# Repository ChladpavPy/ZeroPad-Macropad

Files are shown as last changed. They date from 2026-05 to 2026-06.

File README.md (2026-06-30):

# ZeroPad - Custom Macropad

The pathfinder project is great hardware introduction project, but I wanted to do bit more, that I would use daily - specifically for quick shortcuts as a keyboard to my computer.

I designed a custom PCB in KiCad featuring a 2x3 matrix with 6 mechanical Cherry MX switches, and I also added a 4-pin header for a 0.91 I2C OLED display. The display is intended to show the currently active macro profile (such as gaming Mode or work Mode). The board layout was carefully optimized for standard 1U keycap spacing to avoid keycaps collisions.

## Project Features

* **Microcontroller:** Seeed Studio XIAO RP2040
* **Switches:** 6x Mechanical Cherry MX Switches
* **Display:** 0.91 I2C OLED Display for active mode rendering
* **Status LEDs:** 3x basic LEDs for hardware debugging/status
* **PCB Design:** Custom 2-layer board routed in KiCad with dual Cu GND pours for a clean finish.

## Gallery

### Build Preview
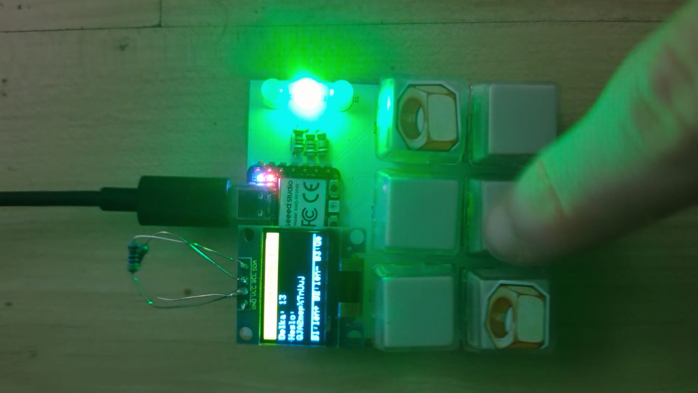
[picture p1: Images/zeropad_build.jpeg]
Build Preview

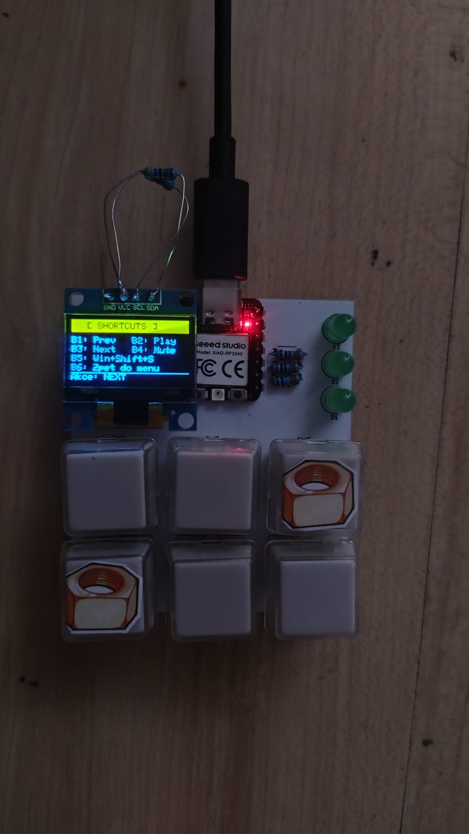
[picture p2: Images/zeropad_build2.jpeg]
Build Preview

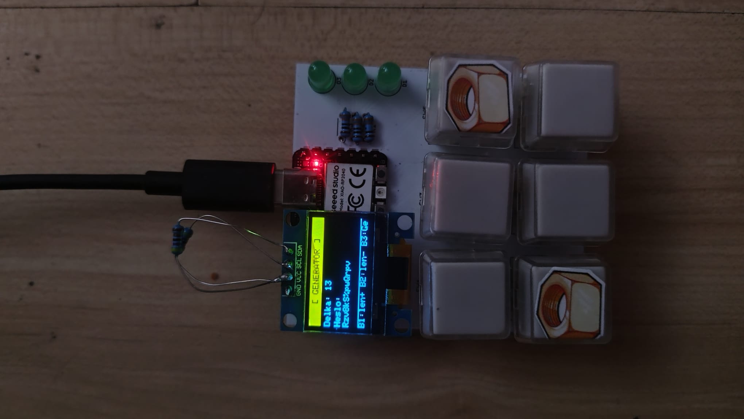
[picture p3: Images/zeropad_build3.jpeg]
Build Preview


### 3D Assembly Renders
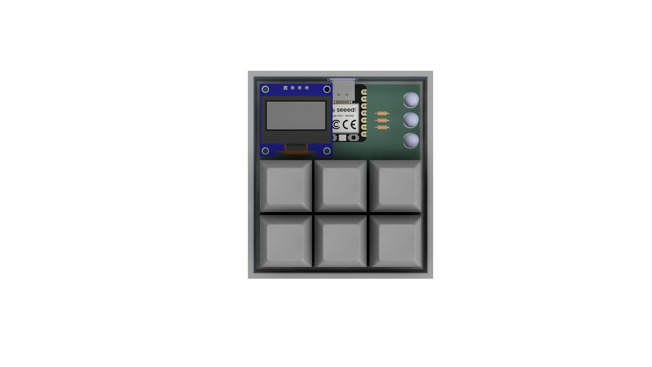
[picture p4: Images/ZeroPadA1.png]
ASSEMBLY_1

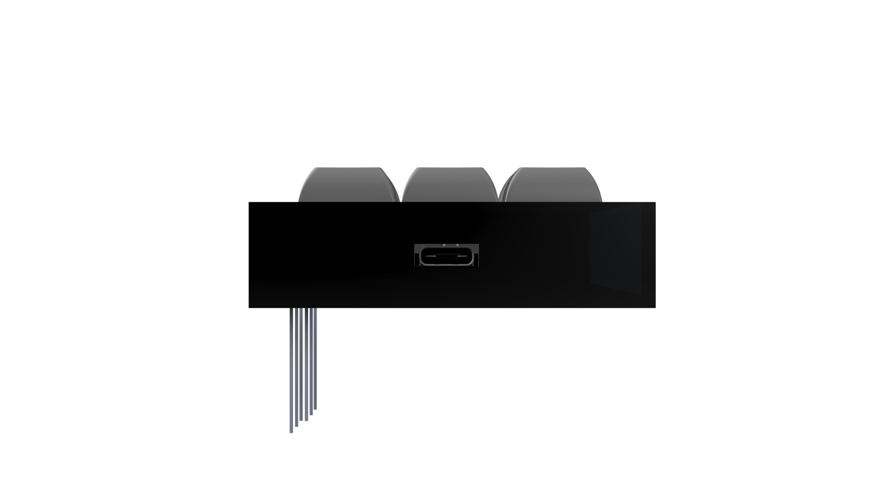
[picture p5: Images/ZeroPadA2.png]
ASSEMBLY_2

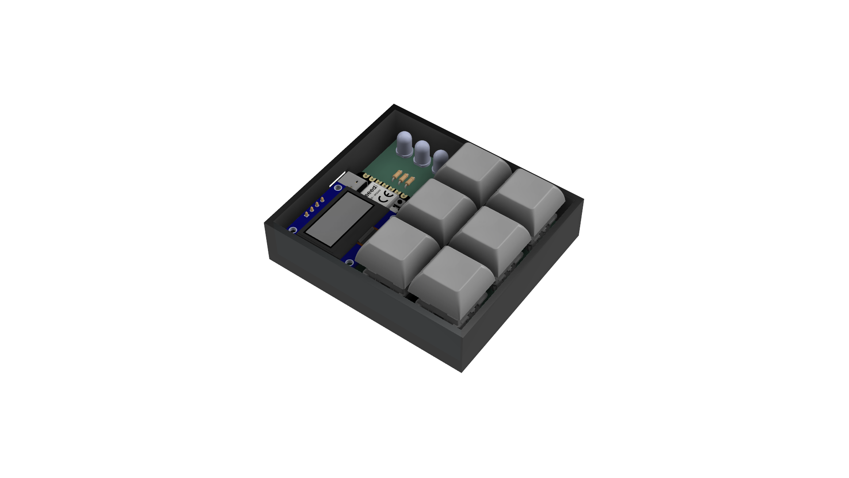
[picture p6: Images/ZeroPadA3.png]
ASSEMBLY_3


### 3D PCB Renders
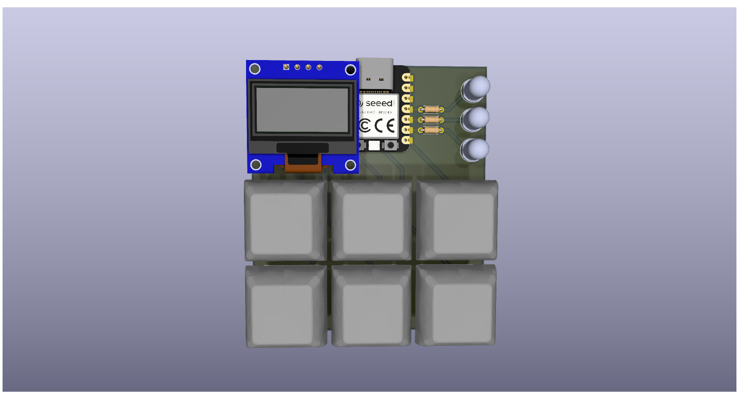
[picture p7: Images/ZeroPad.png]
PCB 3D 1

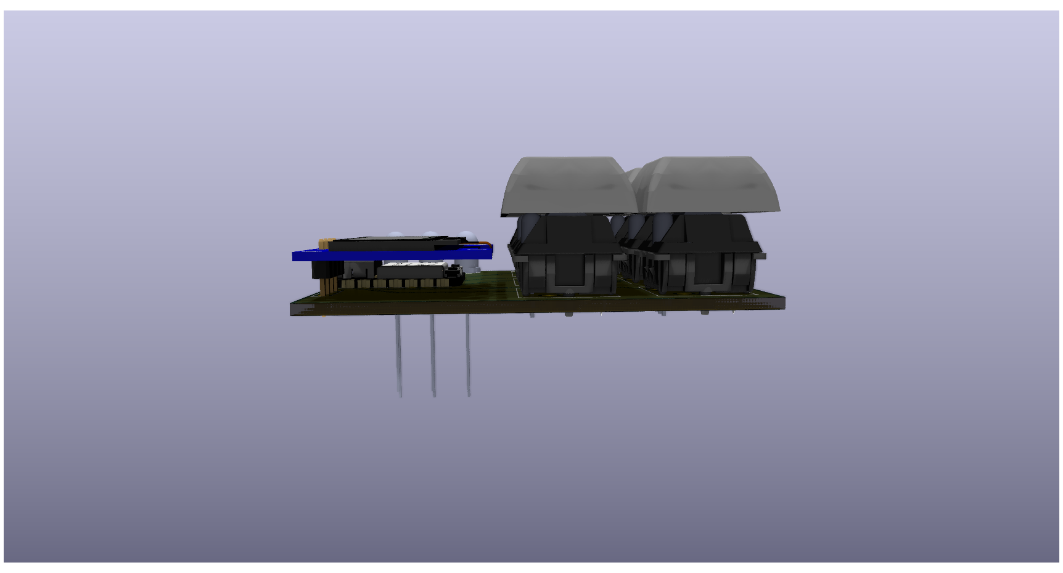
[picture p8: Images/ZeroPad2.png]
PCB 3D 2

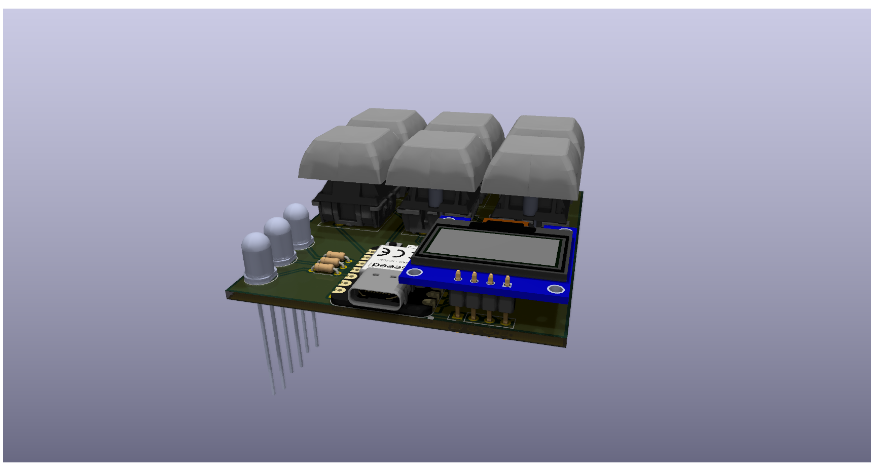
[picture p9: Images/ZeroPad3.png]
PCB 3D 3


### PCB Routing & Schematic
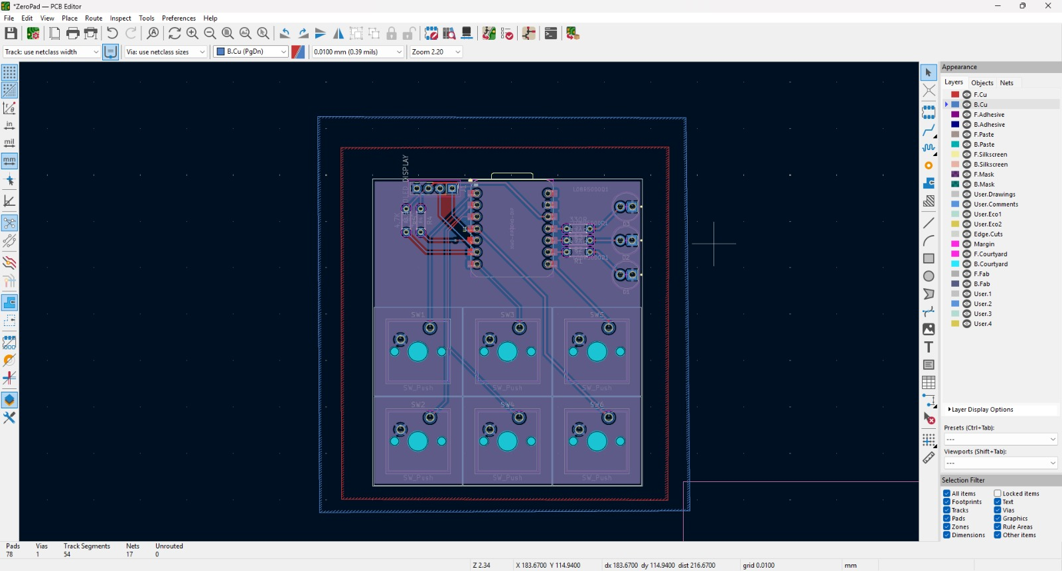
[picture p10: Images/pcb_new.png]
PCB Front

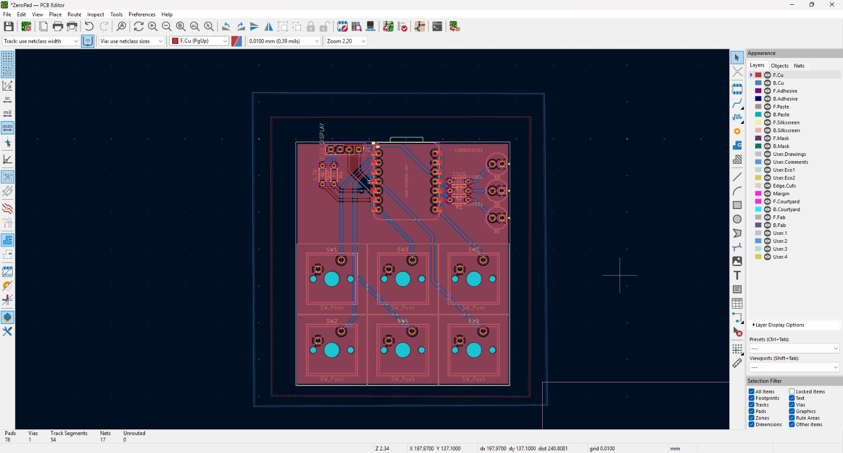
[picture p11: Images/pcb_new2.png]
PCB Back

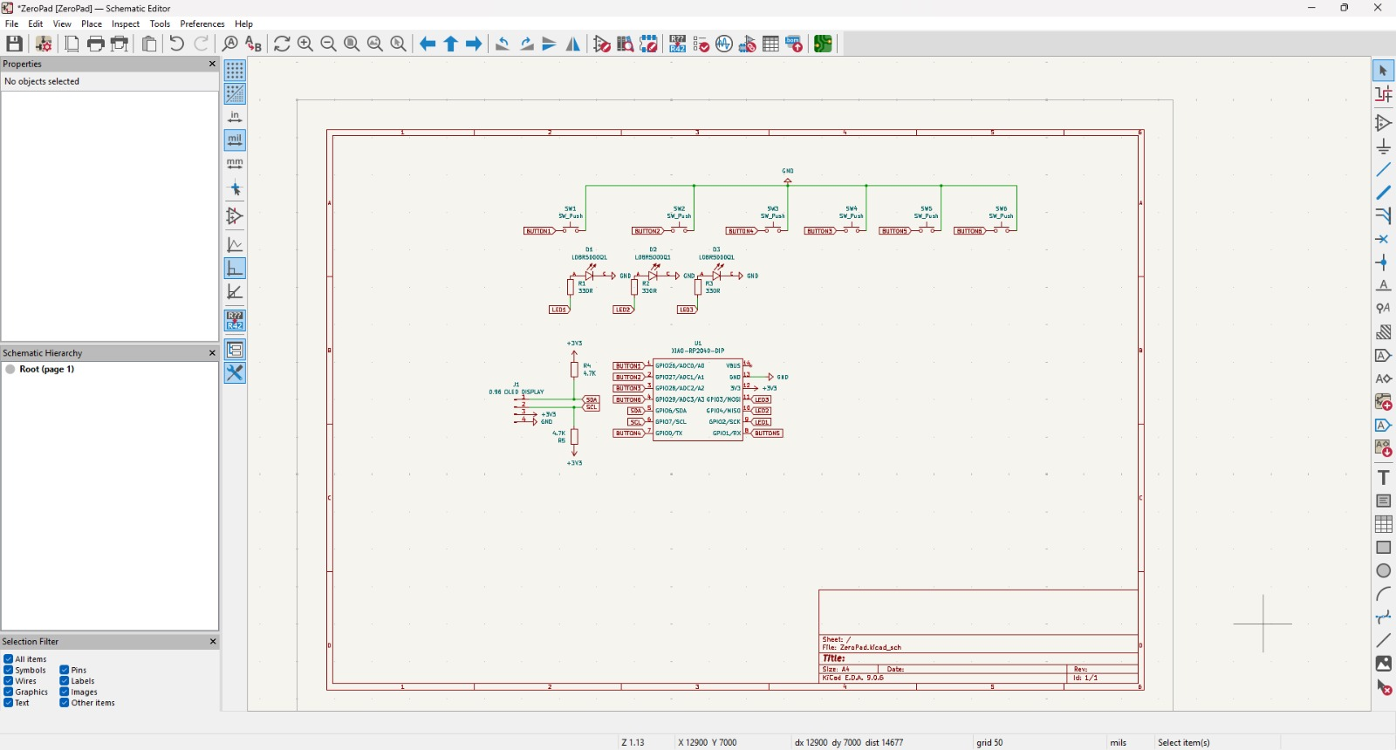
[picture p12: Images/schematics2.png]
Schematic


---

## Bill of Materials (BOM)

| Component | Qty | Purpose / Description | Price (USD) | Link / Distributor |
| :--- | :---: | :--- | :--- | :--- |
| **Custom PCB Manufacture** | 5 | The actual circuit board to solder everything on. Ordered via JLCPCB standard 2-layer service. | ~$4.74 | [JLCPCB](https://jlcpcb.com) |
| **Seeed Studio XIAO RP2040** | 1 | Main microcontroller / brain for the macropad. Small footprint, plenty of GPIOs. | ~$7.88 | [AliExpress](https://a.aliexpress.com/_EyHIJs2) |
| **0.96" I2C OLED Display** | 1 | Screen to show active macro profiles and current modes. | ~$2.00 | [AliExpress](https://a.aliexpress.com/_EGSrJ7g) |
| **Cherry MX Switches (10-pack)** | 1 | Mechanical switches for the macro buttons. | ~$6.08 | [AliExpress](https://a.aliexpress.com/_EuLENRY) |
| **1U Blank Keycaps (10-pack)** | 1 | Standard covers for the mechanical switches. | ~$3.35 | [AliExpress](https://a.aliexpress.com/_Eyx6JJo) |
| **5mm Green LEDs** | 3 | Status LEDs for debugging (Bought locally, link is equivalent). | ~$0.50 | [SparkFun](https://www.sparkfun.com/products/9592) |
| **330 Ohm Resistors** | 3 | Current limiting resistors for the LEDs (Bought locally). | ~$0.50 | [SparkFun](https://www.sparkfun.com/resistor-330-ohm-1-6th-watt-pth.html) |
| **4.7k Ohm Resistors** | 2 | I2C pull-up resistors for stable OLED communication. | ~$0.50 | [Dratek.cz](https://dratek.cz/arduino-platforma/174921-metalizovany-rezistor-4k7-5w-1.html) |

---

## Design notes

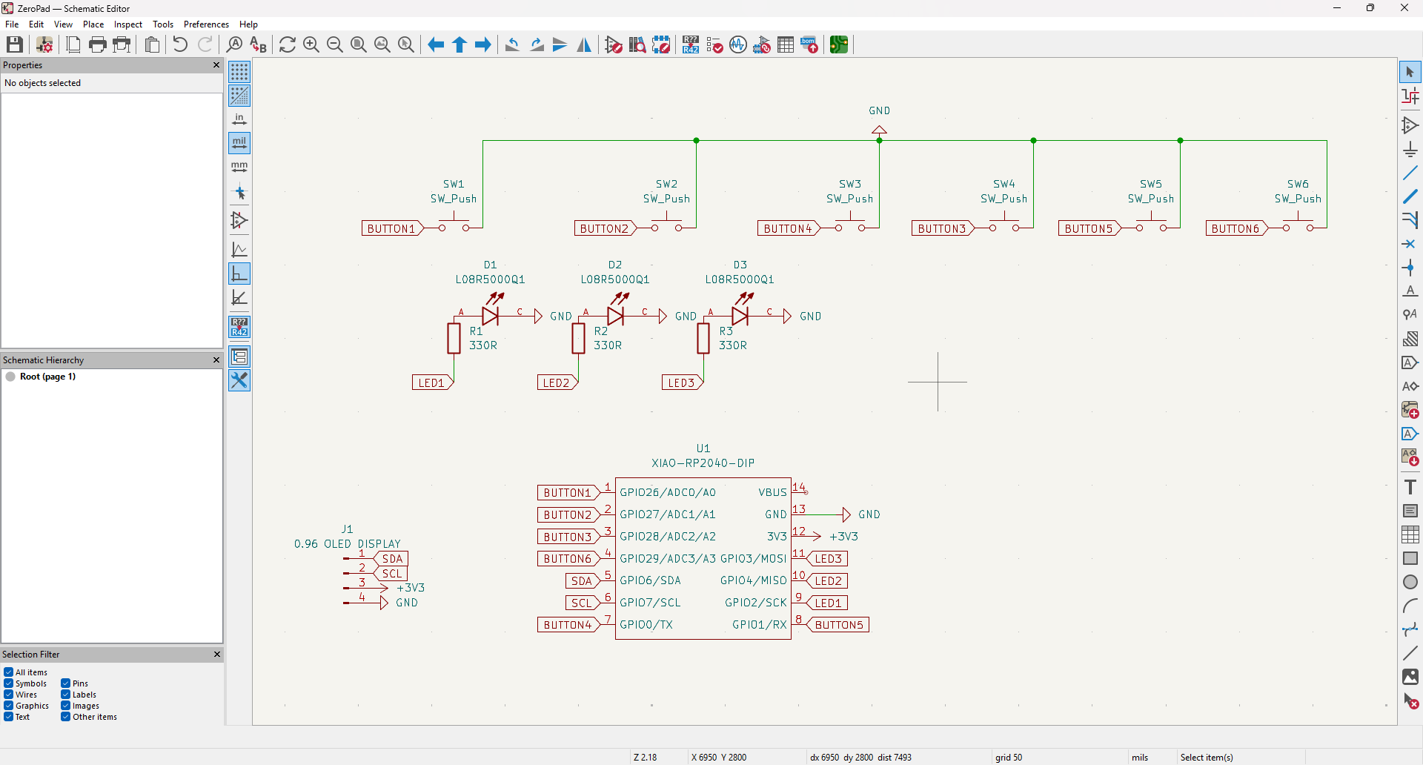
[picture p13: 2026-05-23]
Images/schematics.png

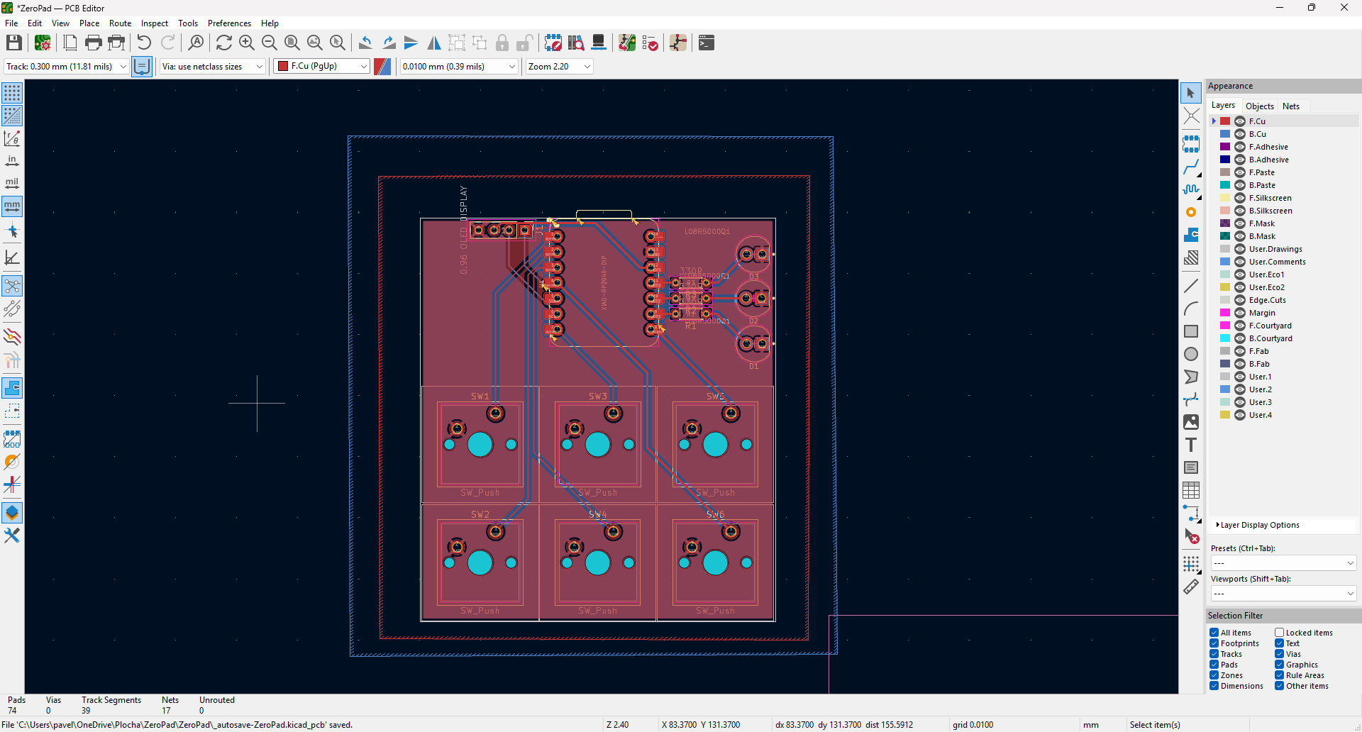
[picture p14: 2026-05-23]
Images/pcb_f.png

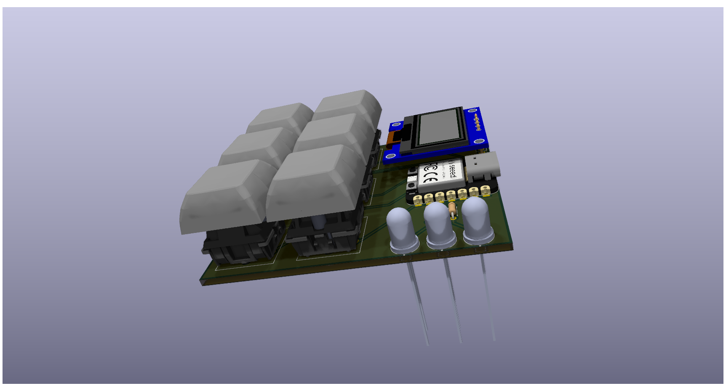
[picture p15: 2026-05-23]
Images/ZeroPad4.png

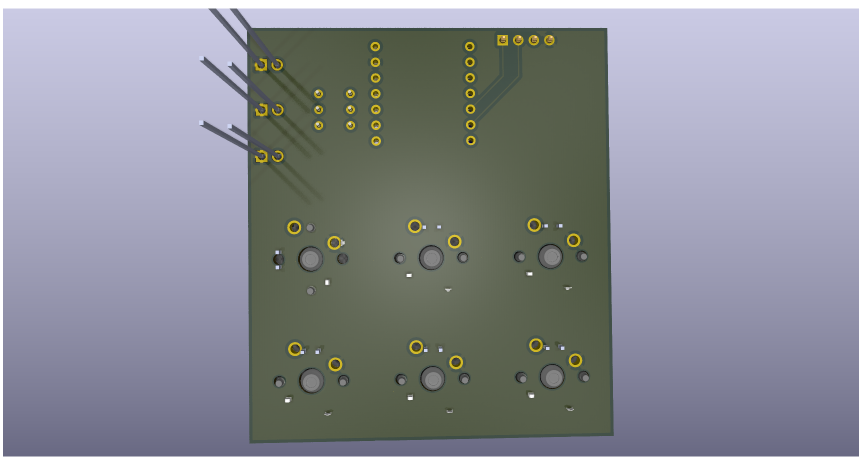
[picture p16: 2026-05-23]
Images/ZeroPad5.png

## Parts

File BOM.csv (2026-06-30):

Component | Qty | Purpose / Description | Price (USD) | Link / Distributor
Custom PCB Manufacture | 5 | The actual circuit board to solder everything on. Ordered via JLCPCB standard 2-layer service. | ~$4.74 | https://jlcpcb.com
Seeed Studio XIAO RP2040 | 1 | Main microcontroller / brain for the macropad. Small footprint, plenty of GPIOs. | ~$7.88 | https://a.aliexpress.com/_EyHIJs2
0.96 I2C OLED Display | 1 | Screen to show active macro profiles and current modes. | ~$2.00 | https://a.aliexpress.com/_EGSrJ7g
Cherry MX Switches (10-pack) | 1 | Mechanical switches for the macro buttons. | ~$6.08 | https://a.aliexpress.com/_EuLENRY
1U Blank Keycaps (10-pack) | 1 | Standard covers for the mechanical switches. | ~$3.35 | https://a.aliexpress.com/_Eyx6JJo
5mm Green LEDs | 3 | Status LEDs for debugging (Bought locally, link is equivalent). | ~$0.50 | https://www.sparkfun.com/products/9592
330 Ohm Resistors | 3 | Current limiting resistors for the LEDs (Bought locally). | ~$0.50 | https://www.sparkfun.com/resistor-330-ohm-1-6th-watt-pth.html
4.7k Ohm Resistors | 2 | I2C pull-up resistors for stable OLED communication. | ~$0.50 | https://dratek.cz/arduino-platforma/174921-metalizovany-rezistor-4k7-5w-1.html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

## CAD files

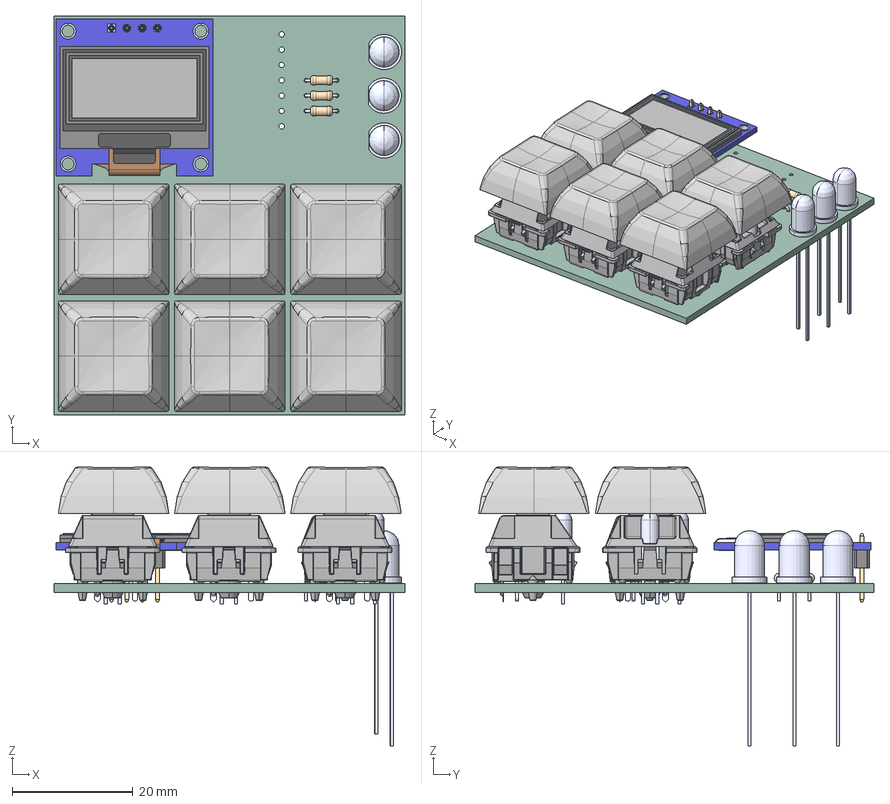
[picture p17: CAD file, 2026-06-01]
3DModels/ZeroPad.step
58.1 x 66.1 x 46.2 mm
Blue_LED_5mm_STEP
DM-OLED096-636_Module
DM-OLED096-636_Panel
MX Öá °´¼ü¡ä_¨¹___¡§1 x 6
MX ס סͥ¨¢¨¬_¡§¡顧__ x 6
MXס ϞñLEDLEDLED x 6
MXÖá ÖáÌå µ×²¿ ¦Ì¡Á2__Ä¬ÈÏ_¨¢2____¨¨_ x 6
֫½ğ__Ĭɏ__¨¨_ x 6
DSA_Keycap_CherryMX x 5
R_Axial_DIN0204_L3.6mm_D1.6mm_P5.08mm_Horizontal x 3
Blue_LED_5mm_STEP (1) x 2
DSA_Keycap_CherryMX (1)
ZeroPad_PCB

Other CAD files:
3DModels/ZeroPad.f3z

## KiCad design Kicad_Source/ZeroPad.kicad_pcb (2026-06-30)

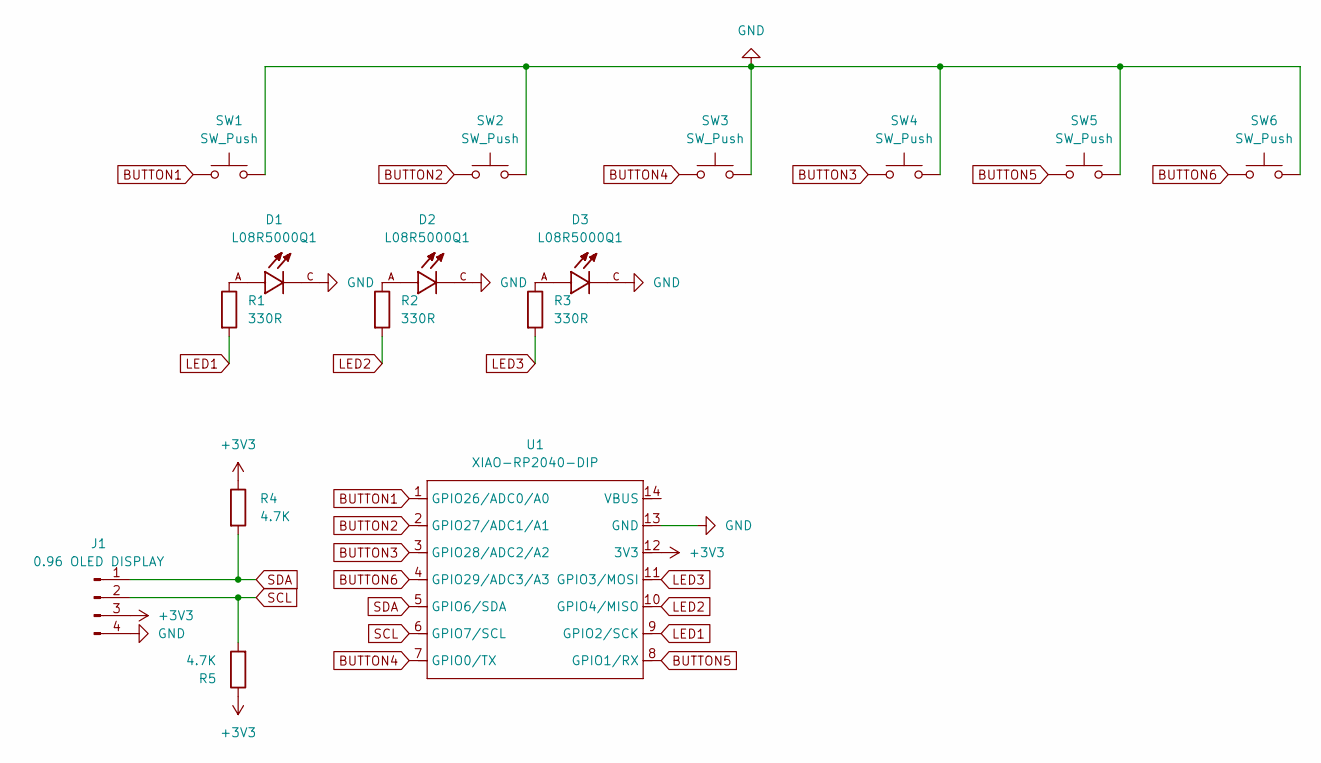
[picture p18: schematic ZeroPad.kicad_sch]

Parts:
D1, D2, D3: L08R5000Q1; LEDRD254W57D500H1070; PARTREV NA
J1: 0.96 OLED DISPLAY; PinHeader_1x04_P2.54mm_Vertical
R1, R2, R3: 330R; R_Axial_DIN0204_L3.6mm_D1.6mm_P5.08mm_Horizontal
R4, R5: 4.7K; R_Axial_DIN0204_L3.6mm_D1.6mm_P5.08mm_Horizontal
SW1, SW2, SW3, SW4, SW5, SW6: SW_Push; SW_Cherry_MX_1.00u_PCB
U1: XIAO-RP2040-DIP; XIAO-RP2040-DIP (1)

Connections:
+3V3: J1.3, R4.1, R5.1, U1.12 (3V3)
BUTTON1: SW1.1, U1.1 (GPIO26/ADC0/A0)
BUTTON2: SW2.1, U1.2 (GPIO27/ADC1/A1)
BUTTON3: SW4.1, U1.3 (GPIO28/ADC2/A2)
BUTTON4: SW3.1, U1.7 (GPIO0/TX)
BUTTON5: SW5.1, U1.8 (GPIO1/RX)
BUTTON6: SW6.1, U1.4 (GPIO29/ADC3/A3)
GND: D1.C, D2.C, D3.C, J1.4, SW1.2, SW2.2, SW3.2, SW4.2, SW5.2, SW6.2, U1.13 (GND)
LED1: R1.2, U1.9 (GPIO2/SCK)
LED2: R2.2, U1.10 (GPIO4/MISO)
LED3: R3.2, U1.11 (GPIO3/MOSI)
unnamed: D1.A, R1.1
unnamed: D2.A, R2.1
unnamed: D3.A, R3.1
SCL: J1.2, R5.2, U1.6 (GPIO7/SCL)
SDA: J1.1, R4.2, U1.5 (GPIO6/SDA)

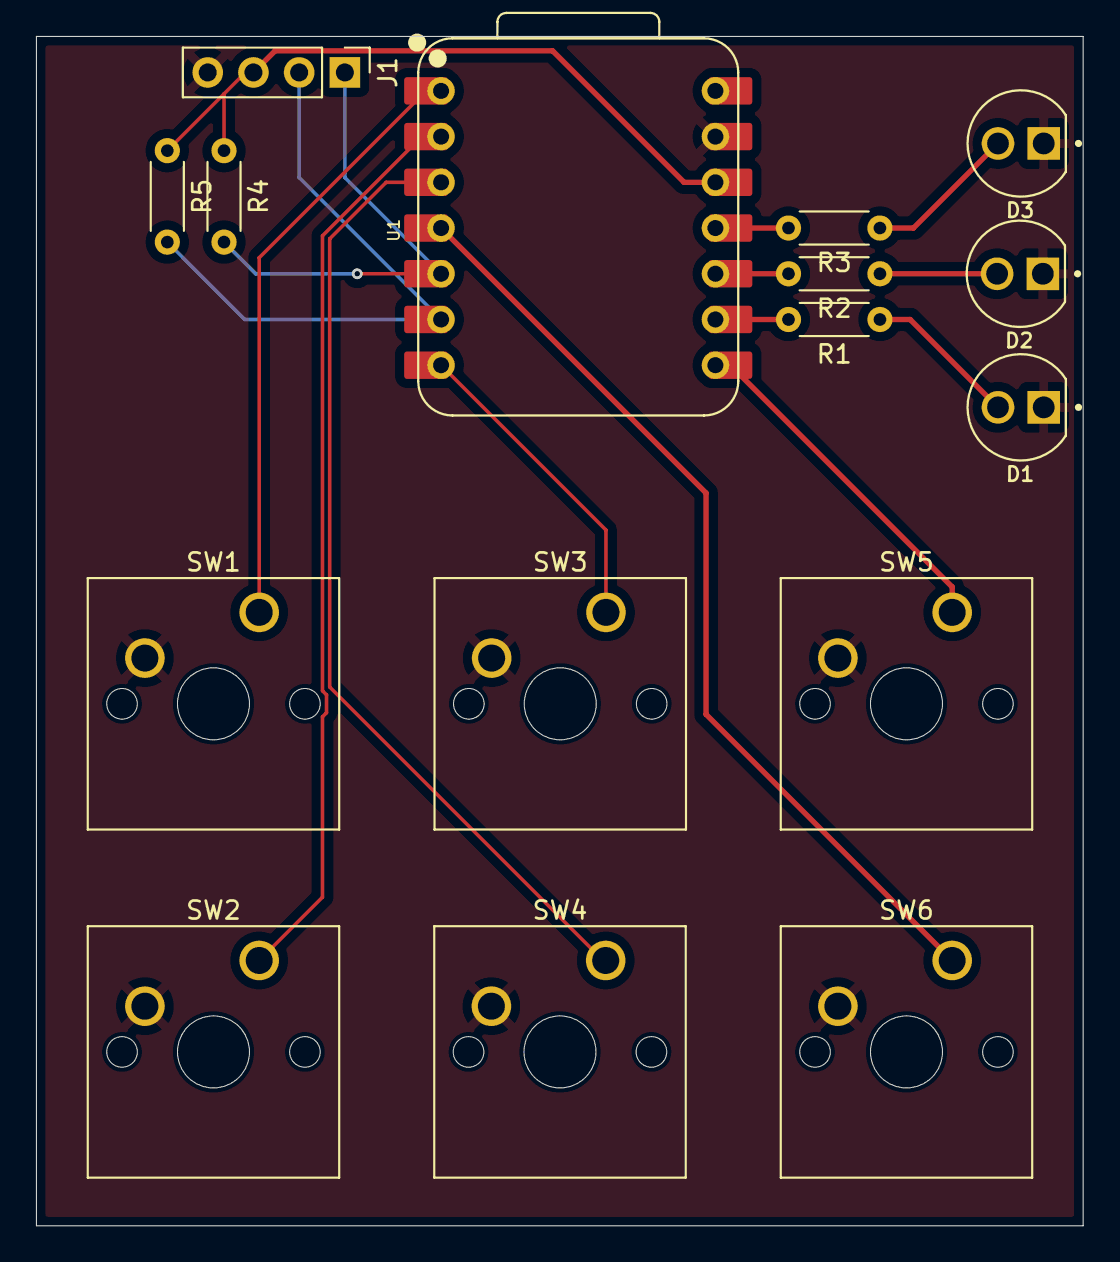
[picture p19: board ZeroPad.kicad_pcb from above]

Board: 2 copper layers, 58.1 x 66.1 mm, 16 parts (0 on the bottom side), 16 nets.

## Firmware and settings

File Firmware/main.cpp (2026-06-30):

#include <Arduino.h>
#include <Wire.h>
#include <Adafruit_GFX.h>
#include <Adafruit_SSD1306.h>
#include <Keyboard.h>

#define MY_SDA 6
#define MY_SCL 7

#define B1 26
#define B2 27
#define B3 28
#define B4 0
#define B5 1
#define B6 29

#define LED1 2
#define LED2 4
#define LED3 3

Adafruit_SSD1306 display(128, 64, &Wire, -1);
bool displayOK = false;

int currentMode = 0;
int menuIndex = 0;
const char* menuLabels[] = {"> Shortcuts", "> Morse code", "> Generator"};

String morseBuffer = "";
String textBuffer = "";
const char* morseTable[] = {
  ".-","-...","-.-.","-..",".","..-.","--.","....","..",
  ".---","-.-",".-..","--","-.","---",".--.","--.-",".-.",
  "...","-","..-","...-",".--","-..-","-.--","--.."
};

int passLen = 13;
String currentPass = "QJA2mep%TrWwJ";
char charset[] = "abcdefghijklmnopqrstuvwxyzABCDEFGHIJKLMNOPQRSTUVWXYZ0123456789!@#$%^&*";

void setup() {
  pinMode(LED1, OUTPUT);
  pinMode(LED2, OUTPUT);
  pinMode(LED3, OUTPUT);
  
  pinMode(B1, INPUT_PULLUP);
  pinMode(B2, INPUT_PULLUP);
  pinMode(B3, INPUT_PULLUP);
  pinMode(B4, INPUT_PULLUP);
  pinMode(B5, INPUT_PULLUP);
  pinMode(B6, INPUT_PULLUP);

  pinMode(MY_SDA, INPUT_PULLUP);
  pinMode(MY_SCL, INPUT_PULLUP);
  delay(10);
  
  Wire.setSDA(MY_SDA);
  Wire.setSCL(MY_SCL);
  Wire.setClock(100000);
  Wire.begin();

  if (display.begin(SSD1306_SWITCHCAPVCC, 0x3C) || display.begin(SSD1306_SWITCHCAPVCC, 0x3D)) {
    displayOK = true;
  }
  
  Keyboard.begin();
  randomSeed(analogRead(26));
  delay(1000);
  drawMenu();
}

void loop() {
  if (currentMode == 0) {
    if (digitalRead(B1) == LOW) { menuIndex--; if(menuIndex < 0) menuIndex = 2; drawMenu(); delay(200); }
    if (digitalRead(B2) == LOW) { menuIndex++; if(menuIndex > 2) menuIndex = 0; drawMenu(); delay(200); }
    if (digitalRead(B3) == LOW) { currentMode = menuIndex + 1; drawMode(); delay(200); }
  } 
  else if (currentMode == 1) {
    if (digitalRead(B6) == LOW) { currentMode = 0; drawMenu(); delay(200); }
    if (digitalRead(B1) == LOW) { Keyboard.press(KEY_SCAN_PREVIOUS); Keyboard.releaseAll(); delay(200); }
    if (digitalRead(B2) == LOW) { Keyboard.press(KEY_PLAY_PAUSE); Keyboard.releaseAll(); delay(200); }
    if (digitalRead(B5) == LOW) { Keyboard.press(KEY_LEFT_GUI); Keyboard.press(KEY_LEFT_SHIFT); Keyboard.press('s'); Keyboard.releaseAll(); delay(200); }
  } 
  else if (currentMode == 2) {
    if (digitalRead(B6) == LOW) { currentMode = 0; drawMenu(); delay(200); }
    if (digitalRead(B1) == LOW) { morseBuffer += "."; drawMorse(); delay(200); }
    if (digitalRead(B2) == LOW) { morseBuffer += "-"; drawMorse(); delay(200); }
    if (digitalRead(B3) == LOW) {
      for (int i = 0; i < 26; i++) {
        if (morseBuffer == morseTable[i]) {
          textBuffer += (char)('A' + i);
          Keyboard.print((char)('a' + i));
          break;
        }
      }
      morseBuffer = "";
      drawMorse();
      delay(200);
    }
    if (digitalRead(B4) == LOW) { morseBuffer = ""; drawMorse(); delay(200); }
    if (digitalRead(B5) == LOW) { textBuffer += " "; Keyboard.print(" "); drawMorse(); delay(200); }
  } 
  else if (currentMode == 3) {
    if (digitalRead(B6) == LOW) { currentMode = 0; drawMenu(); delay(200); }
    if (digitalRead(B1) == LOW) { passLen++; if(passLen > 25) passLen = 25; drawGenerator(); delay(200); }
    if (digitalRead(B2) == LOW) { passLen--; if(passLen < 4) passLen = 4; drawGenerator(); delay(200); }
    if (digitalRead(B3) == LOW) { 
      currentPass = "";
      for(int i=0; i<passLen; i++) {
        currentPass += charset[random(0, strlen(charset))];
      }
      drawGenerator(); 
      delay(200); 
    }
    if (digitalRead(B4) == LOW) { Keyboard.print(currentPass); delay(200); }
  }
}

void drawMenu() {
  if(!displayOK) return;
  display.clearDisplay();
  display.setTextColor(SSD1306_WHITE);
  display.setTextSize(1);
  display.setCursor(0,0);
  display.println("ZEROPAD OS");
  display.println("----------------");
  for(int i = 0; i < 3; i++) {
    if(i == menuIndex) {
      display.print("-> ");
    } else {
      display.print("   ");
    }
    display.println(menuLabels[i]);
  }
  display.display();
}

void drawMode() {
  if(currentMode == 1) drawShortcuts();
  if(currentMode == 2) drawMorse();
  if(currentMode == 3) drawGenerator();
}

void drawShortcuts() {
  if(!displayOK) return;
  display.clearDisplay();
  display.setCursor(0,0);
  display.println("SHORTCUTS");
  display.println("----------------");
  display.println("B1: Prev Track");
  display.println("B2: Play/Pause");
  display.println("B5: Win+Shift+S");
  display.println("B6: Zpet do Menu");
  display.display();
}

void drawMorse() {
  if(!displayOK) return;
  display.clearDisplay();
  display.setCursor(0,0);
  display.println("MORSE CODE");
  display.println("----------------");
  display.print("Znak: "); 
  display.println(morseBuffer);
  display.print("Text: "); 
  display.println(textBuffer);
  display.display();
}

void drawGenerator() {
  if(!displayOK) return;
  display.clearDisplay();
  display.setCursor(0,0);
  display.println("[ GENERATOR ]");
  display.print("Delka: ");
  display.println(passLen);
  display.println("Heslo:");
  display.println(currentPass);
  display.setCursor(0, 56);
  display.println("B1:len+ B2:len- B3:Gen");
  display.display();
}

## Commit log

2026-05-23 Revise README with project overview and specifications
    Expanded project details, features, and BOM in README.
2026-06-01 Add 3D assembly renders to README
    Added 3D assembly renders to the gallery section.
2026-06-01 Fix PCB 3D image links in README
    Updated PCB 3D render images in README.
2026-06-01 Replace PCB 3D images with updated versions
    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
2026-06-08 Revise BOM with new components and descriptions
    Updated BOM.csv to include new components and their details.
    [BOM.csv]
